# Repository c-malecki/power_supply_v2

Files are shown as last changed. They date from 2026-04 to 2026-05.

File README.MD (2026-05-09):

# Power Supply V2 (Prototype)

## Project Background

Building my own power supply has has been an ongoing and iterative project to explore and learn embedded systems. Designing and building my own tools seemed like a great way to work on something with a real use case and grow my knowledge and skill via iterative design and progressive loading of new concepts and methodologies in stages.

### Previous Iterations

The [first version](https://github.com/c-malecki/power_supply) served as a discovery phase, utilizing hardware modules primarily in order to gain a high-level understanding of power supply design and electrical engineering/embedded systems. Due to complications and limitations of the component selection (*particularly I2C issues with many undocumented modules and whether they have internal pull-up resistors*) and having learned enough to make more informed choices, I started working on V2 as the real prototype.

<figure>
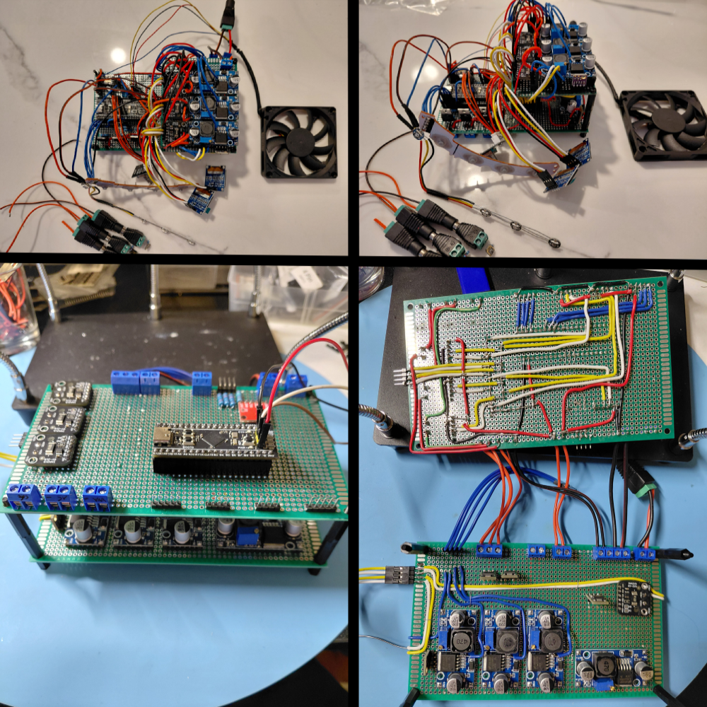
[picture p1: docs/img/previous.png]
Previous Iterations
  
  <figcaption>Some previous iterations and layouts that inevitably became a rat's nest.</figcaption>
</figure>

### V2 Learning Goals:

- __Use EDA software to create schematic diagrams__: Use KiCad 9 to create schematics, revise the design over the course of the project, and learn best practices in schematic diagramming
- __Design circuits using discrete component selections__: Hand select components and perform the calculations required to support intended operation as opposed to hardware modules (*with the exception of reusing OLED and temperature sensor modules*)
- __Increase datasheet and documentation fluency__: Relying on vendor sources primarily for application considerations and calculations

### V2 Exclusions:

- __PCB design:__ I am assembling this prototype using perfboard and handsoldering due to ease of error correction and rearrangement of circuits
- __Advanced Data Features:__ Although data will be read and displayed, I am leaving out advanced integrations like real-time communication with a host PC for logging and analyzing data. I intend to do a "V3" where I will do PCB design and add in support for more complex firmware features.

## V2 Core Features

*This list is subject to change as I continue to work through the prototyping process.*

### Power Rails
- Fixed 3.3V and 5V rails for external loads
- Variable 5V to 18V rail for external load
- Independent output for simultaneous connections
- PID control loop to ensure consistent and accurate output of power rails

### Safety Systems
- Continuous power and temperature monitoring
- Hardware and firmware based protections for reverse polarity, back EMF, overvoltage, overcurrent, and overtemperature
- Firmware controlled shutoffs in stages depending on severity of a fault (*e.g. individual power rail shutoff for external connections, full power rail shutoff for internal and external connections, full system shutoff*)
- RGB LED status indicators and debug blink codes
- Warning and error displays

### User Interface
- OLED for system menu containing configuration settings
- OLED for data display screens such as operating conditions
- Buttons for toggling external rails on/off and cycling through data display screens
- Rotary encoder for navigating system menus and making selections

## Hardware Design

### Component Selection

- [STM32G474RE Nucleo](https://www.st.com/resource/en/datasheet/stm32g474cb.pdf)
- 20V 3.25A Laptop Charging Brick with added 3A slow-blow fuse
- [TPS54302 buck converters](https://www.ti.com/lit/ds/symlink/tps54302.pdf)
- [MCP1700 LDOs](https://ww1.microchip.com/downloads/en/DeviceDoc/MCP1700-Data-Sheet-20001826F.pdf)
- [TPS22918 high side switches](https://www.ti.com/lit/ds/symlink/tps22918.pdf)
- [Voltage buffer](https://www.ti.com/lit/ds/symlink/sn74ahct125.pdf)
- [INA180Ax current sensors](https://www.ti.com/lit/ds/symlink/ina180.pdf)
- [SHT31-D temperature sensors](https://sensirion.com/media/documents/213E6A3B/63A5A569/Datasheet_SHT3x_DIS.pdf)
- [SSD1306 OLEDs](https://goldenmorninglcd.com/wp-content/plugins/pdf-poster/pdfjs-new/web/viewer.html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)
- [WS2812B LEDs](https://cdn.sparkfun.com/assets/e/6/1/f/4/WS2812B-LED-datasheet.pdf)

### Block Diagram

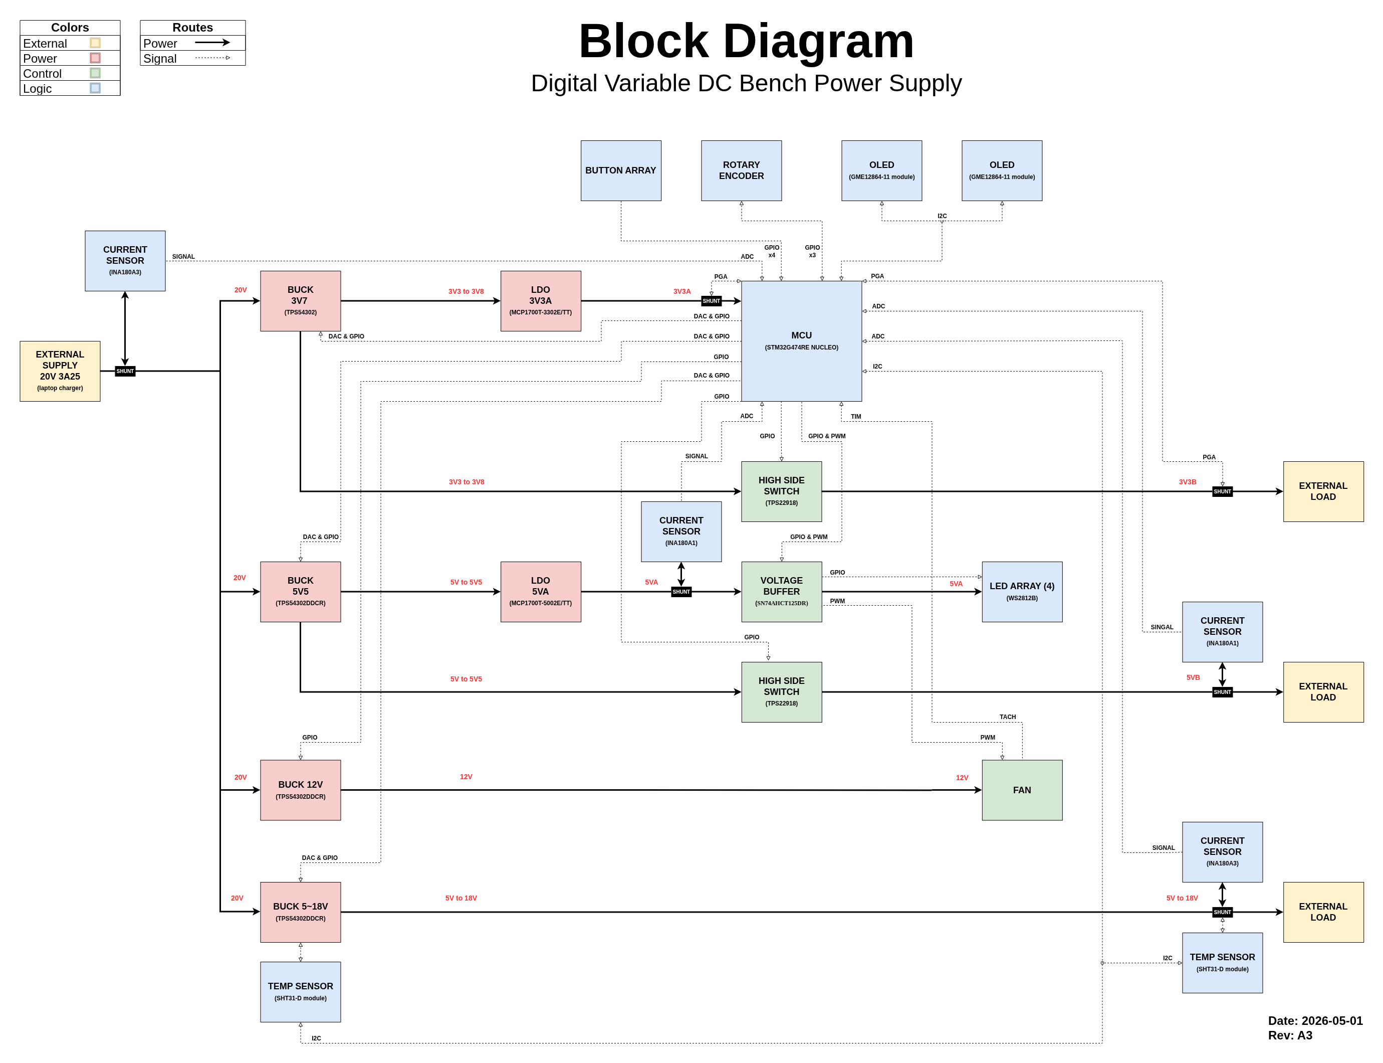
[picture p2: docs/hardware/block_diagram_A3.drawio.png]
Block Diagram


### Schematic

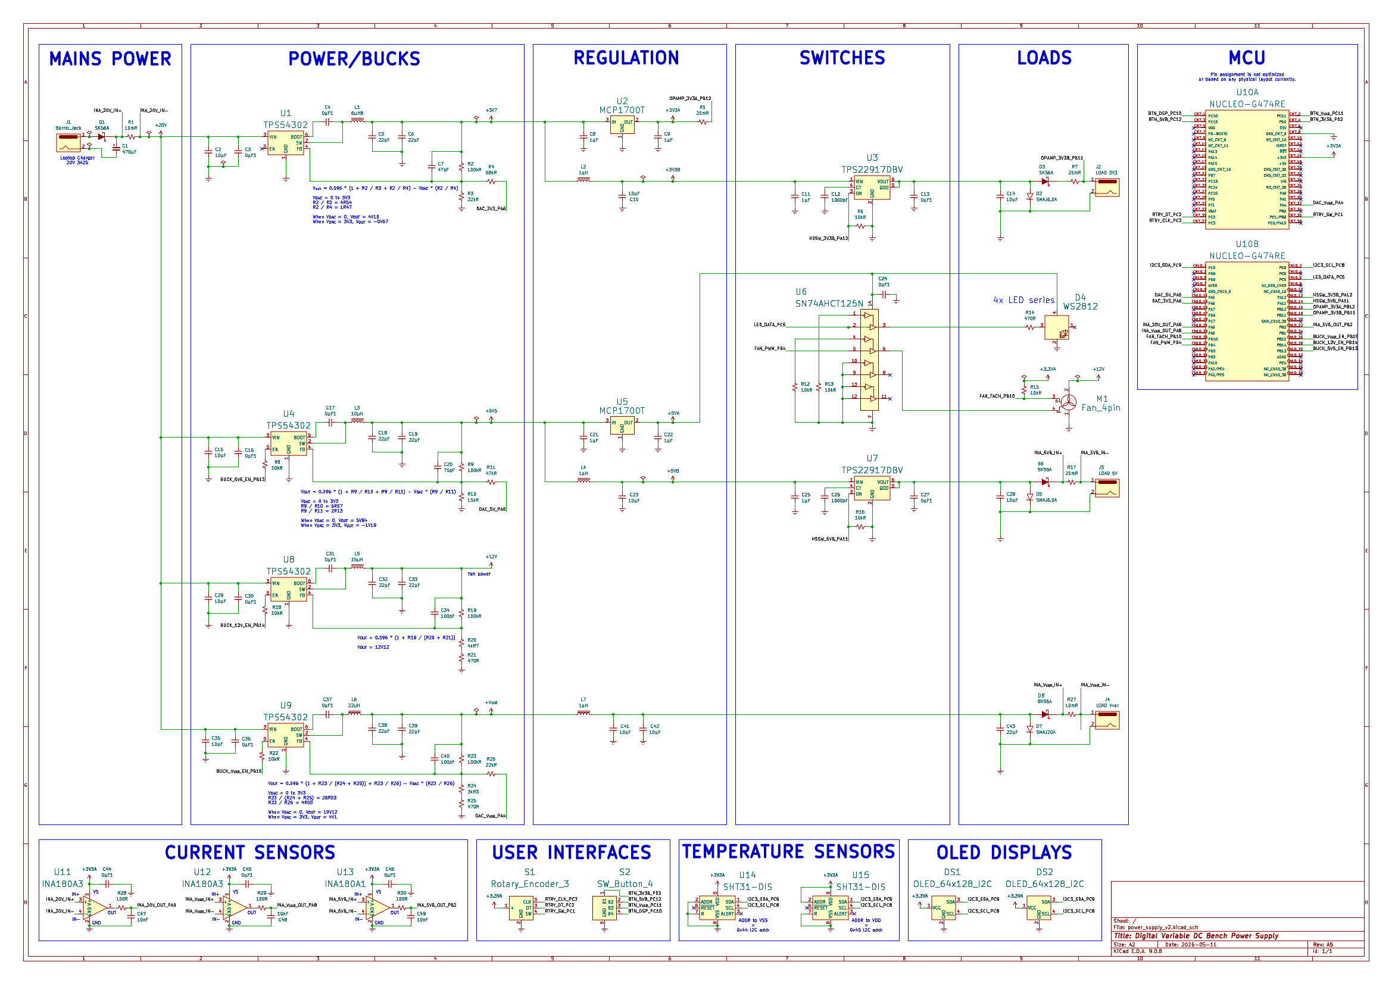
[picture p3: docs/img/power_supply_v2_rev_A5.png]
Schematic


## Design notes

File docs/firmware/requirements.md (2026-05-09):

bucks on/off
hssw on/off

current/voltage readings

temperature readings

change fan speed from temp

safety switches from current/voltage

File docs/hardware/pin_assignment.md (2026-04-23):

# Pin Assignments

## Overview

| Qty | GPIO Mode | PU/PD | Prph & Func |
| --- | --- | --- | --- |
| 2x | EXTI RE | PU | Rotary SW, Rotary DT |
| 4x | EXTI FE | PU | Button Array |
| 1x | Input | PU | Rotary CLK |
| 1x | AF DAC | ? | Vvar Buck EN |
| 1x | ? | ? | LED data |
| 3x | Output PP | ? | Fixed Bucks EN |
| 2x | AF PP | None | Fan Tach, Fan PWM
| 2x | AF OD | None | I2C: SCL + SDA |
| 2x | AF PGA ? | ? | 3V3 shunts |
| 4x | AF ADC ? | ? | 5V, 12V, Vvar shunts |

## By Peripheral

### Rotary Encoder

| MCU Pin | Prph Pin | GPIO Mode | PU/PD |
| --- | --- | --- | --- |
| ? | SW | EXTI Rising-Edge | Pull-up |
| ? | DT | EXTI Rising-Edge | Pull-up |
| ? | CLK | Input | Pull-up |

### Button Array

| MCU Pin | Prph Pin | GPIO Mode | PU/PD |
| --- | --- | --- | --- |
| ? | 1 | EXTI Falling-Edge | Pull-up |
| ? | 2 | EXTI Falling-Edge | Pull-up |
| ? | 3 | EXTI Falling-Edge | Pull-up |
| ? | 4 | EXTI Falling-Edge | Pull-up |

### Buck Converters

| MCU Pin | Prph Pin | GPIO Mode | PU/PD |
| --- | --- | --- | --- |
| ? | EN | Output Push-Pull | ? |
| ? | EN | Output Push-Pull | ? |
| ? | EN | Output Push-Pull | ? |

### Current Sensors

| MCU Pin | Prph Pin | GPIO Mode | PU/PD |
| --- | --- | --- | --- |
| ? | 1 Out | AF ADC ? | ? |
| ? | 1 Out | AF ADC ? | ? |
| ? | 1 Out | AF ADC ? | ? |
| ? | 1 Out | AF ADC ? | ? |

## Protocol

### I2C

### Temperature Sensors

| MCU Pin | Prph Pin | GPIO Mode | PU/PD |
| --- | --- | --- | --- |
| ? | 1 Out | AF ADC ? | ? |
| ? | 1 Out | AF ADC ? | ? |
| ? | 1 Out | AF ADC ? | ? |
| ? | 1 Out | AF ADC ? | ? |

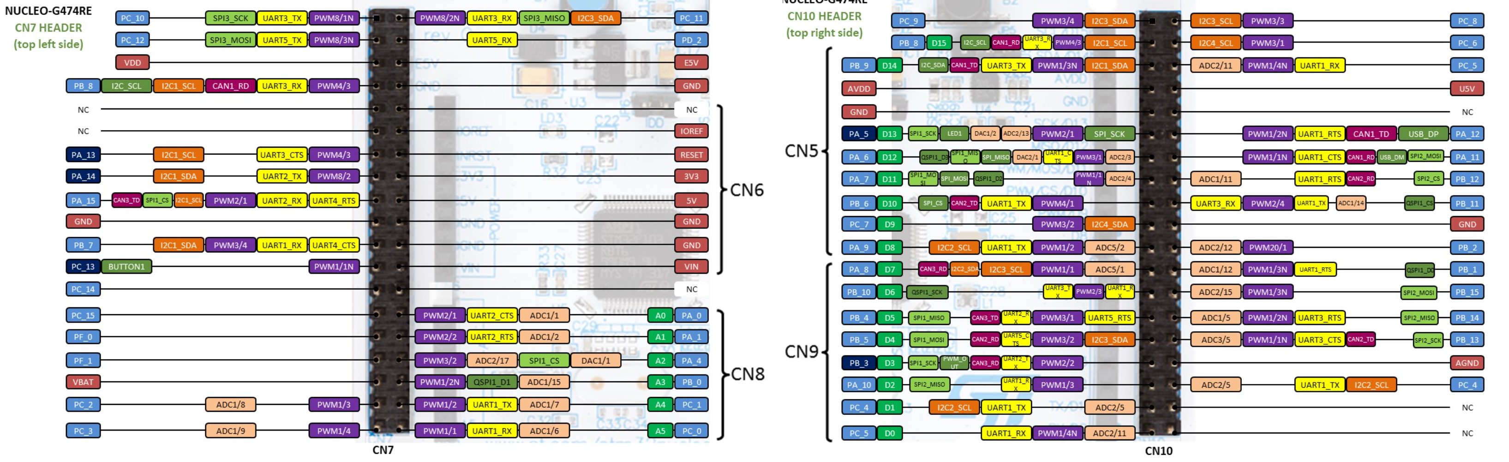
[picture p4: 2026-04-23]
docs/datasheets/microcontroller/STM32G474RE_Pinout.png

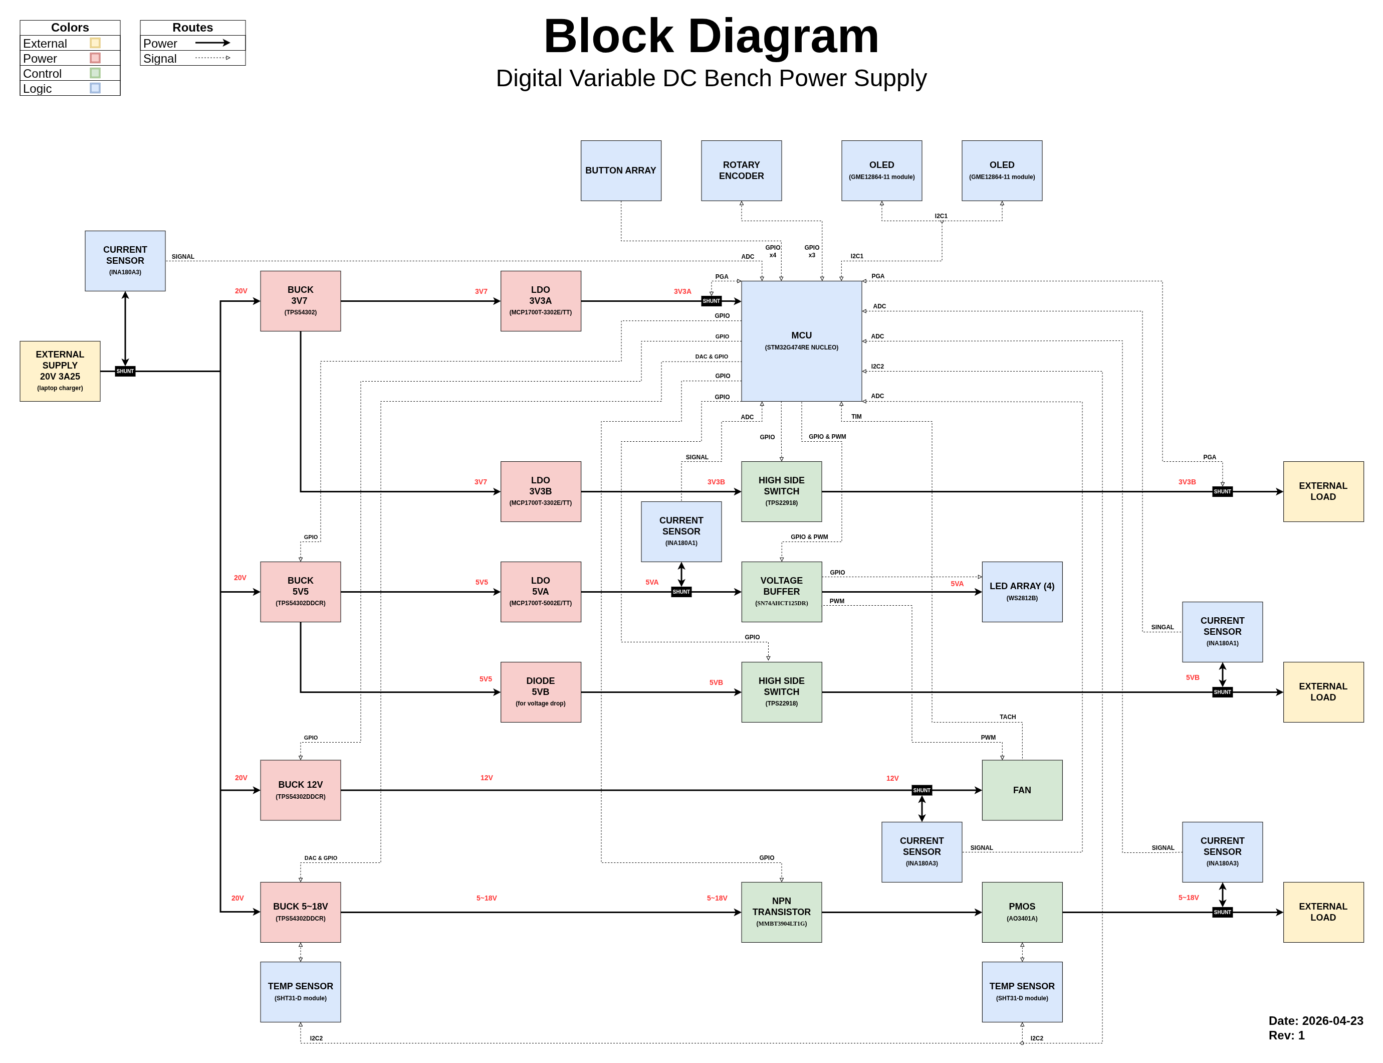
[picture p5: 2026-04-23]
docs/hardware/block_diagram_A1.png

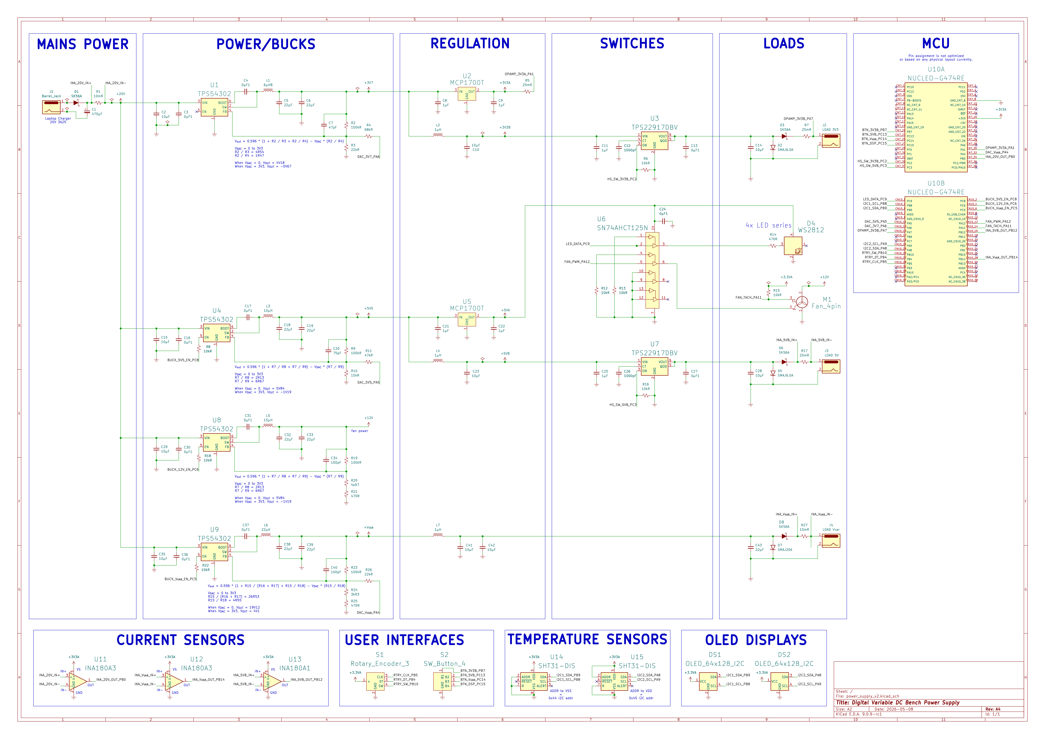
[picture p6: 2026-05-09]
docs/img/power_supply_v2_rev_A4.png

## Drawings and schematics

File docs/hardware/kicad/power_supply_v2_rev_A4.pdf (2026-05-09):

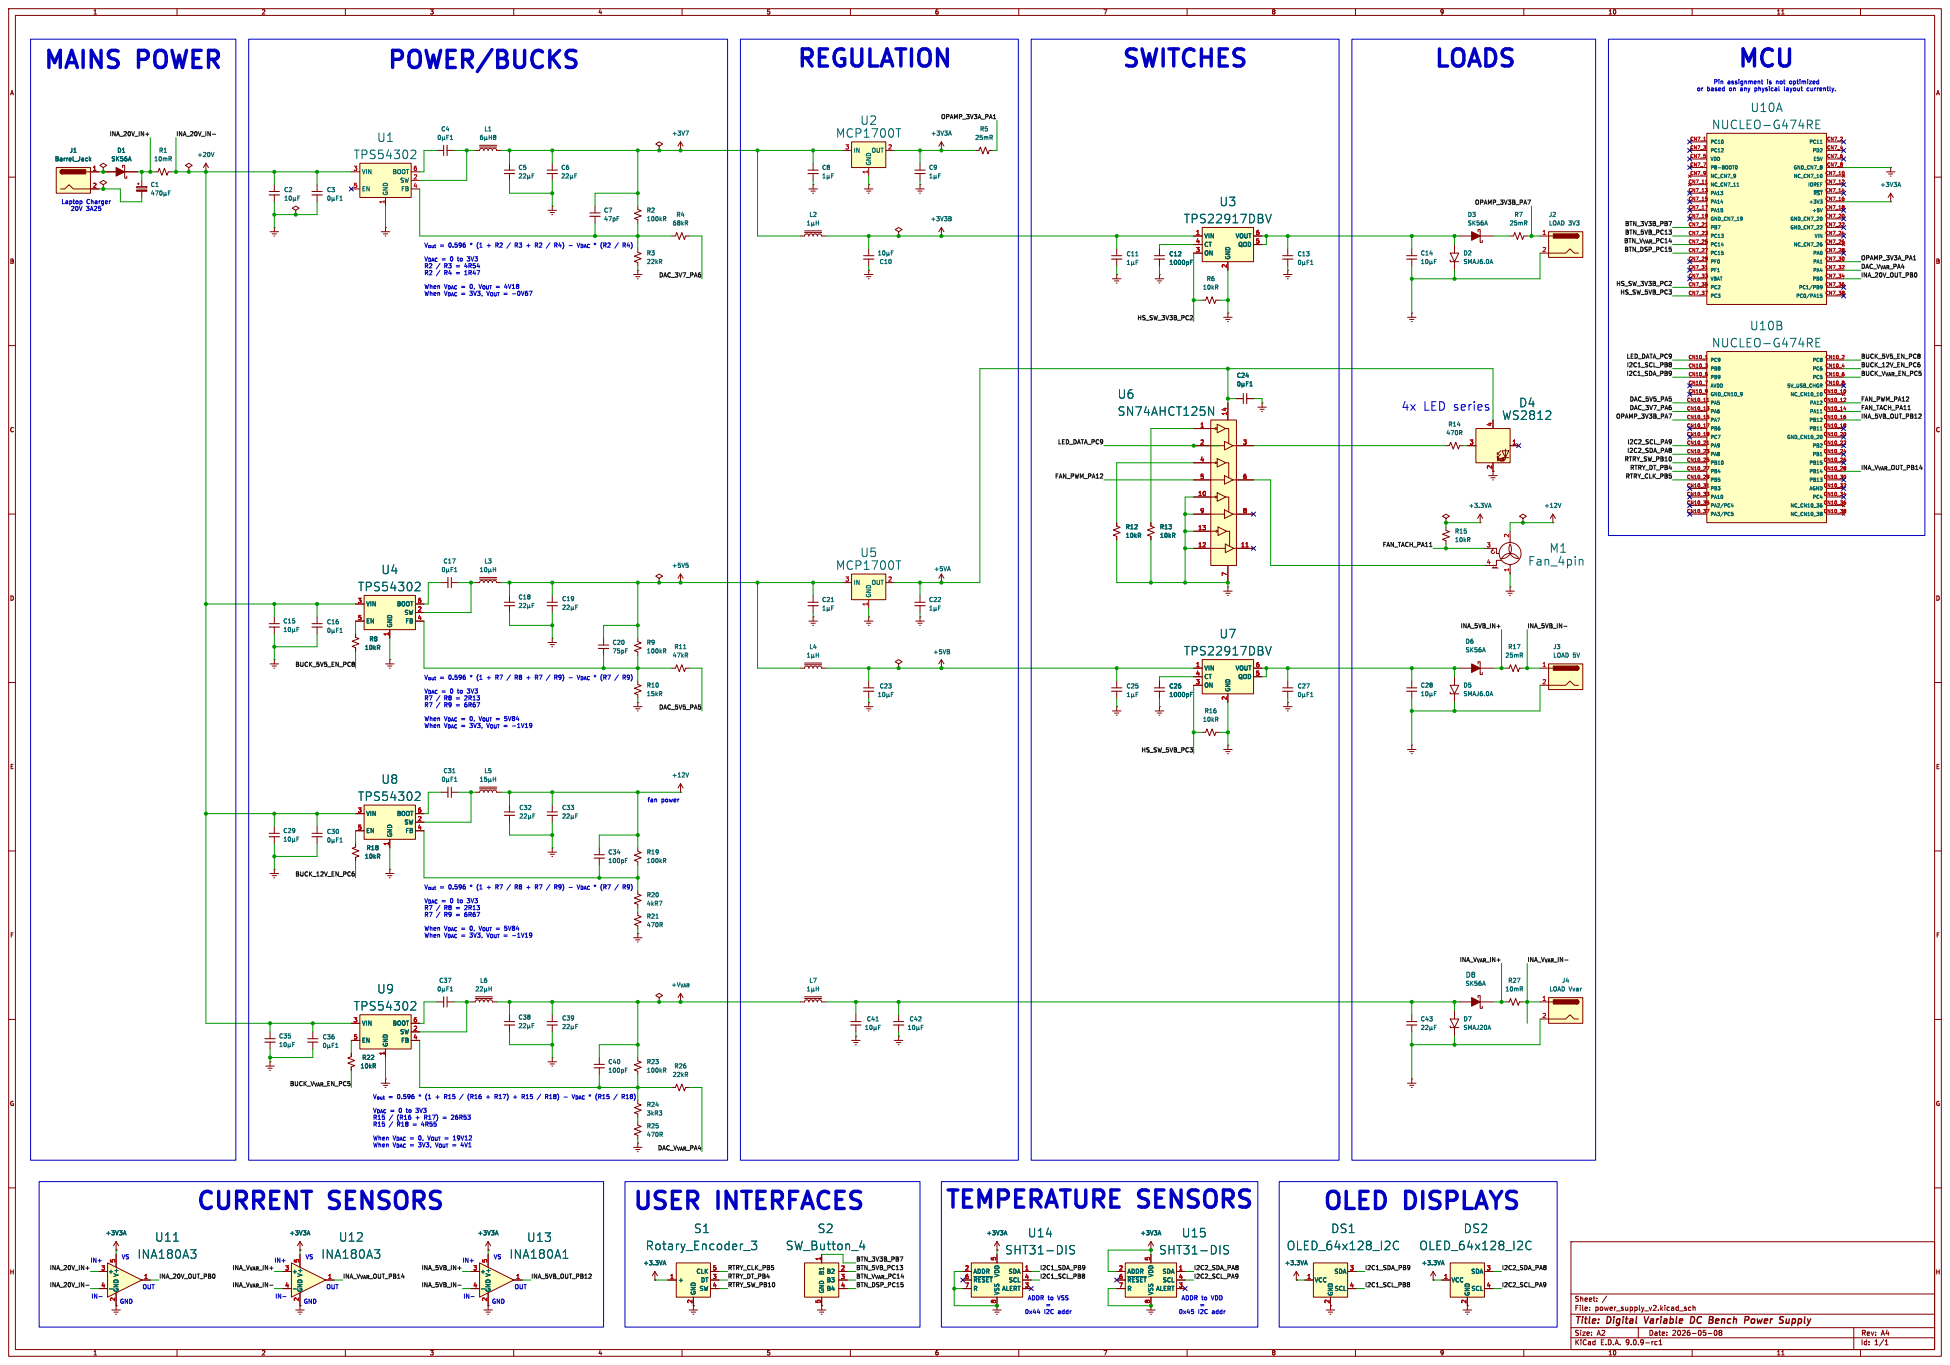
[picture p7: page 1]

0x44 I2C addr OUT MAINS POWER

V_{DAC} = 0 to 3V3 R7 / R8 = 2R13 R7 / R9 = 6R67 When V_{DAC} = 0, V_{OUT} = 5V84 When V_{DAC} = 3V3, V_{OUT} = -1V19

V_{DAC} = 0 to 3V3 R7 / R8 = 2R13 R7 / R9 = 6R67 When V_{DAC} = 0, V_{OUT} = 5V84 When V_{DAC} = 3V3, V_{OUT} = -1V19 OUT

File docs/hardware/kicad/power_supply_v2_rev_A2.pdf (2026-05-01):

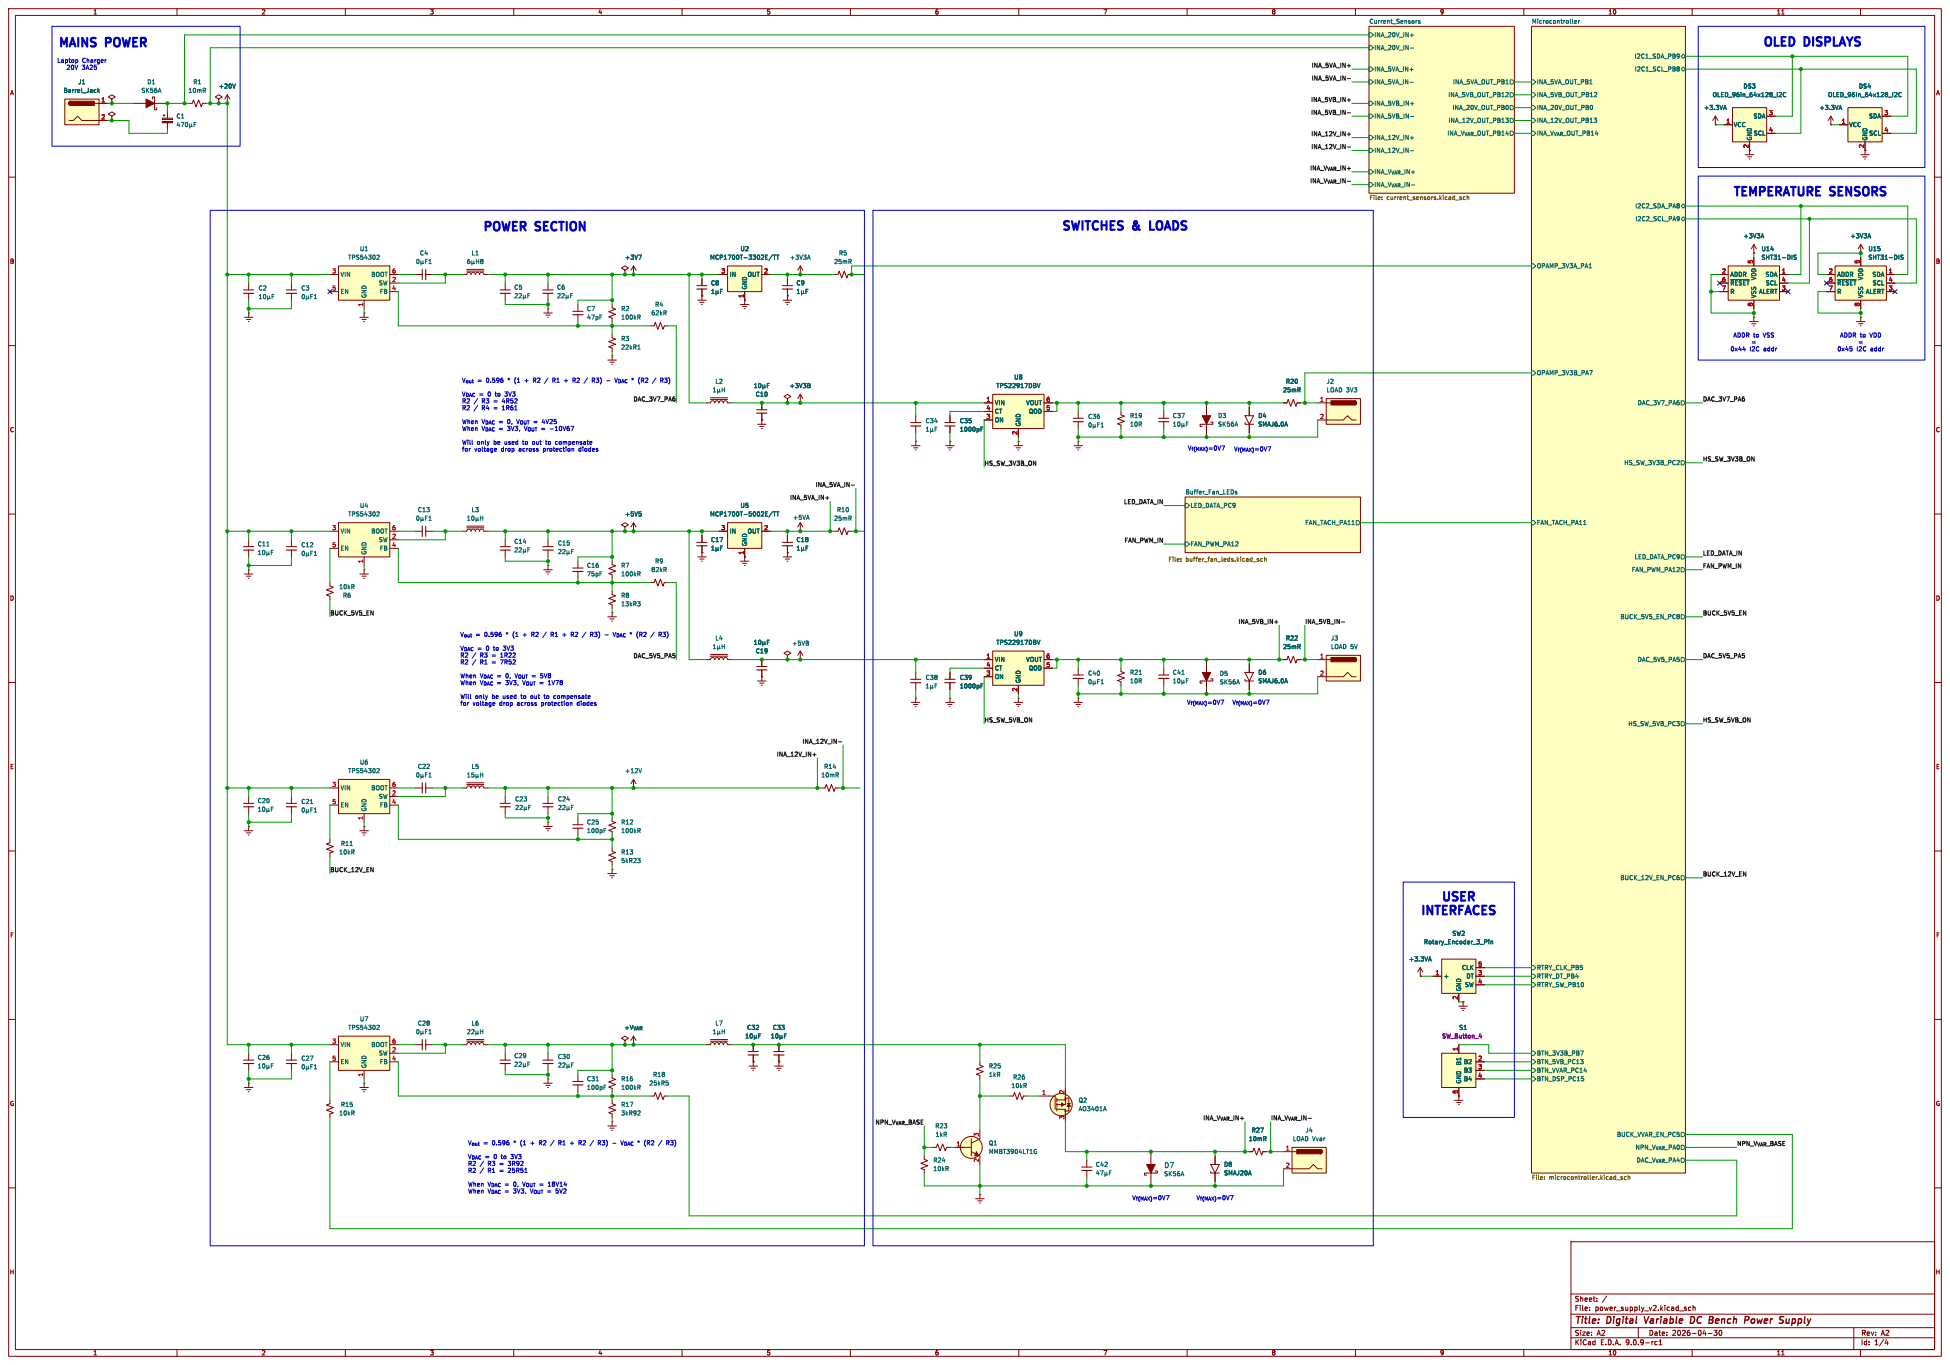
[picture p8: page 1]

Laptop Charger 20V 3A25 MAINS POWER

POWER SECTION
alter modules or remove the resistors. V_{out}= 0.596 * (1 + R2 / R1 + R2 / R3) - V_{DAC} * (R2 / R3)

V_{DAC} = 0 to 3V3 R2 / R3 = 4R52 R2 / R4 = 1R61 When V_{DAC} = 0, V_{OUT} = 4V25 When V_{DAC} = 3V3, V_{OUT} = -10V67 Will only be used to out to compensate

V_{DAC} = 0 to 3V3 R2 / R3 = 1R22 R2 / R1 = 7R52 When V_{DAC} = 0, V_{OUT} = 5V8 When V_{DAC} = 3V3, V_{OUT} = 1V78 Will only be used to out to compensate

V_{DAC} = 0 to 3V3 R2 / R3 = 3R92 R2 / R1 = 25R51 When V_{DAC} = 0, V_{OUT} = 18V14 When V_{DAC} = 3V3, V_{OUT} = 5V2

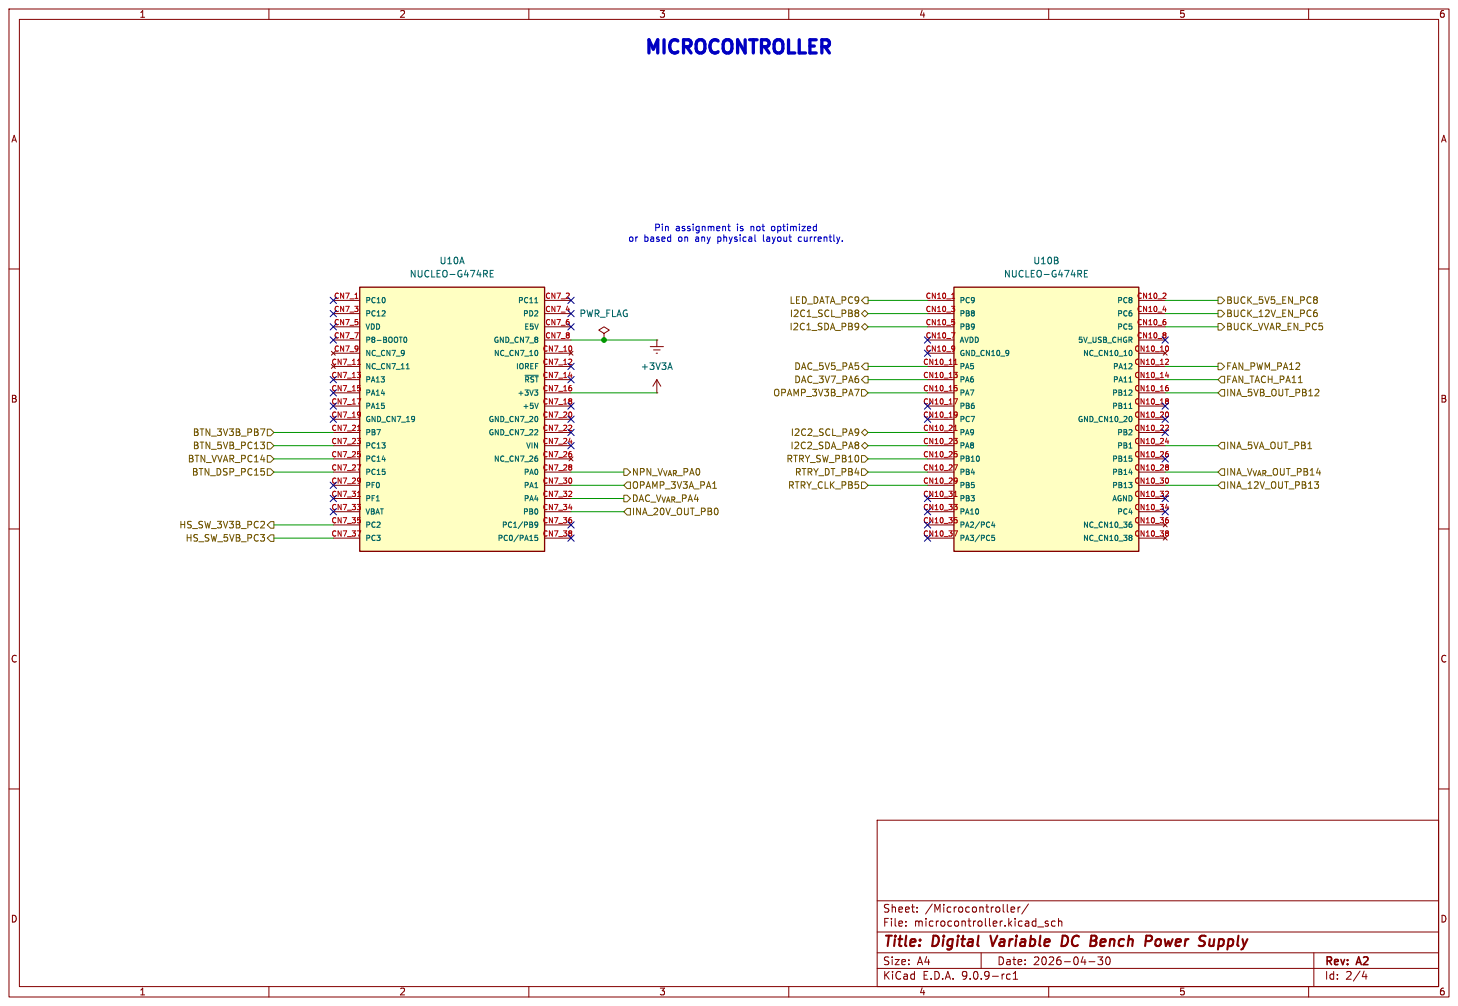
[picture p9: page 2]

File: microcontroller.kicad_sch Sheet: /Microcontroller/
Id: 2/4 Title: Digital Variable DC Bench Power Supply

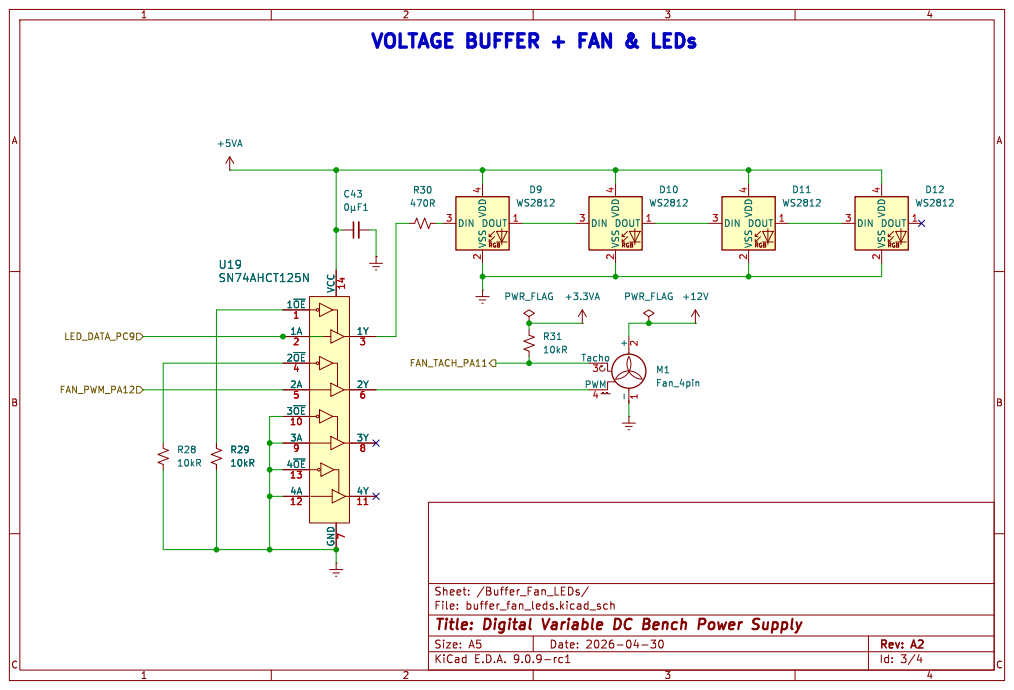
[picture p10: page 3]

11 U19 SN74AHCT125N

Id: 3/4 Title: Digital Variable DC Bench Power Supply

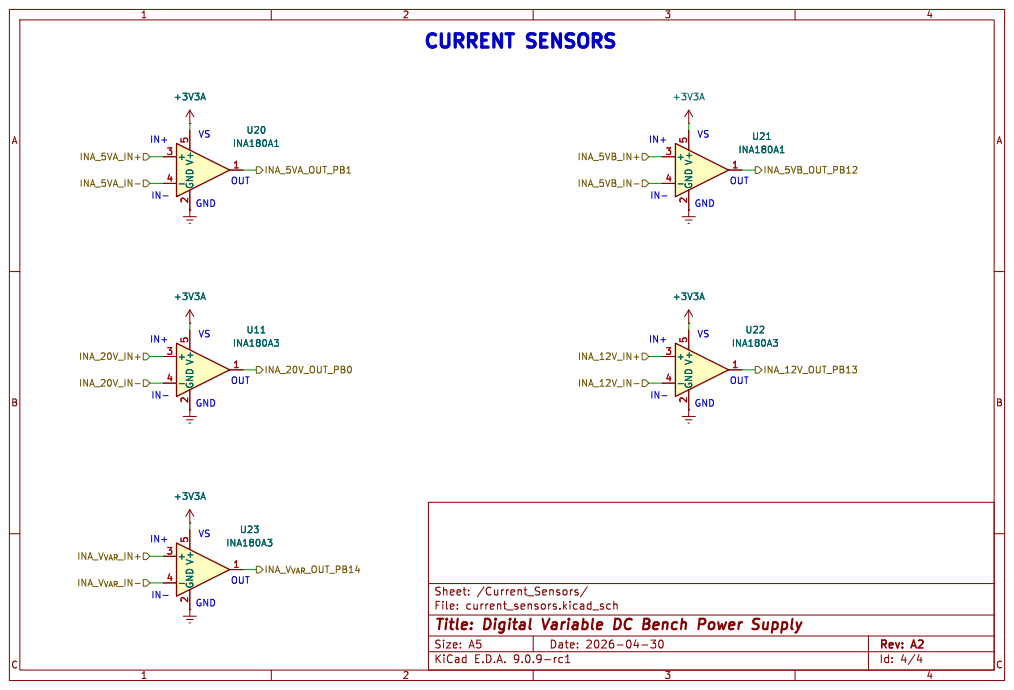
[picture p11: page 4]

File: current_sensors.kicad_sch Sheet: /Current_Sensors/
Id: 4/4 Title: Digital Variable DC Bench Power Supply

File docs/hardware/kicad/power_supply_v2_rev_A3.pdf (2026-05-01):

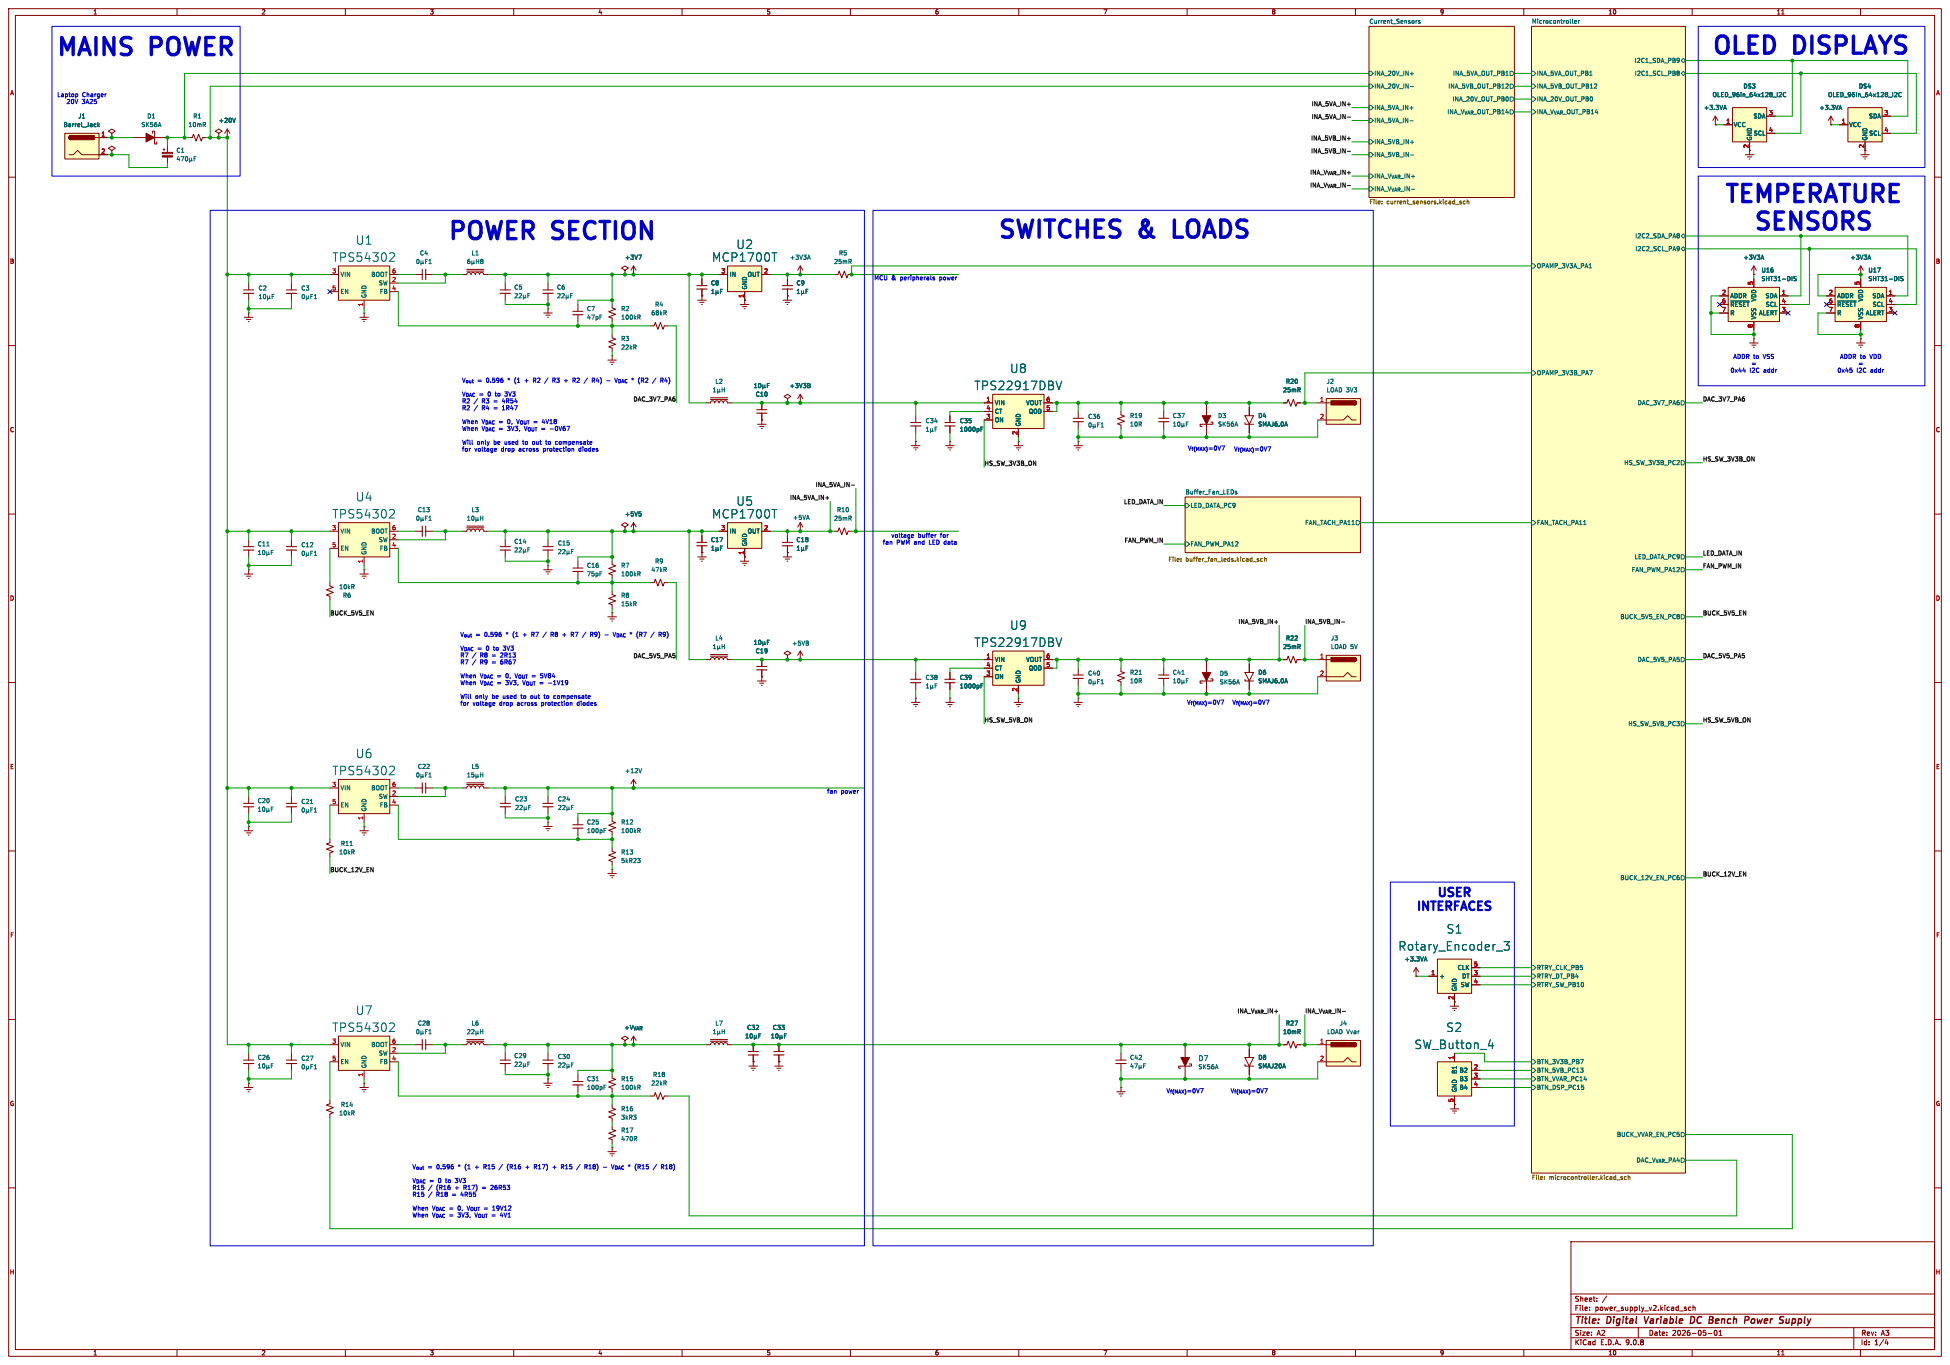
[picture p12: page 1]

alter modules or remove the resistors. OLED DISPLAYS

V_{DAC} = 0 to 3V3 R2 / R3 = 4R54 R2 / R4 = 1R47 When V_{DAC} = 0, V_{OUT} = 4V18 When V_{DAC} = 3V3, V_{OUT} = -0V67 Will only be used to out to compensate

V_{DAC} = 0 to 3V3 R7 / R8 = 2R13 R7 / R9 = 6R67 When V_{DAC} = 0, V_{OUT} = 5V84 When V_{DAC} = 3V3, V_{OUT} = -1V19 Will only be used to out to compensate

V_{DAC} = 0 to 3V3 R15 / (R16 + R17) = 26R53 R15 / R18 = 4R55 When V_{DAC} = 0, V_{OUT} = 19V12 When V_{DAC} = 3V3, V_{OUT} = 4V1

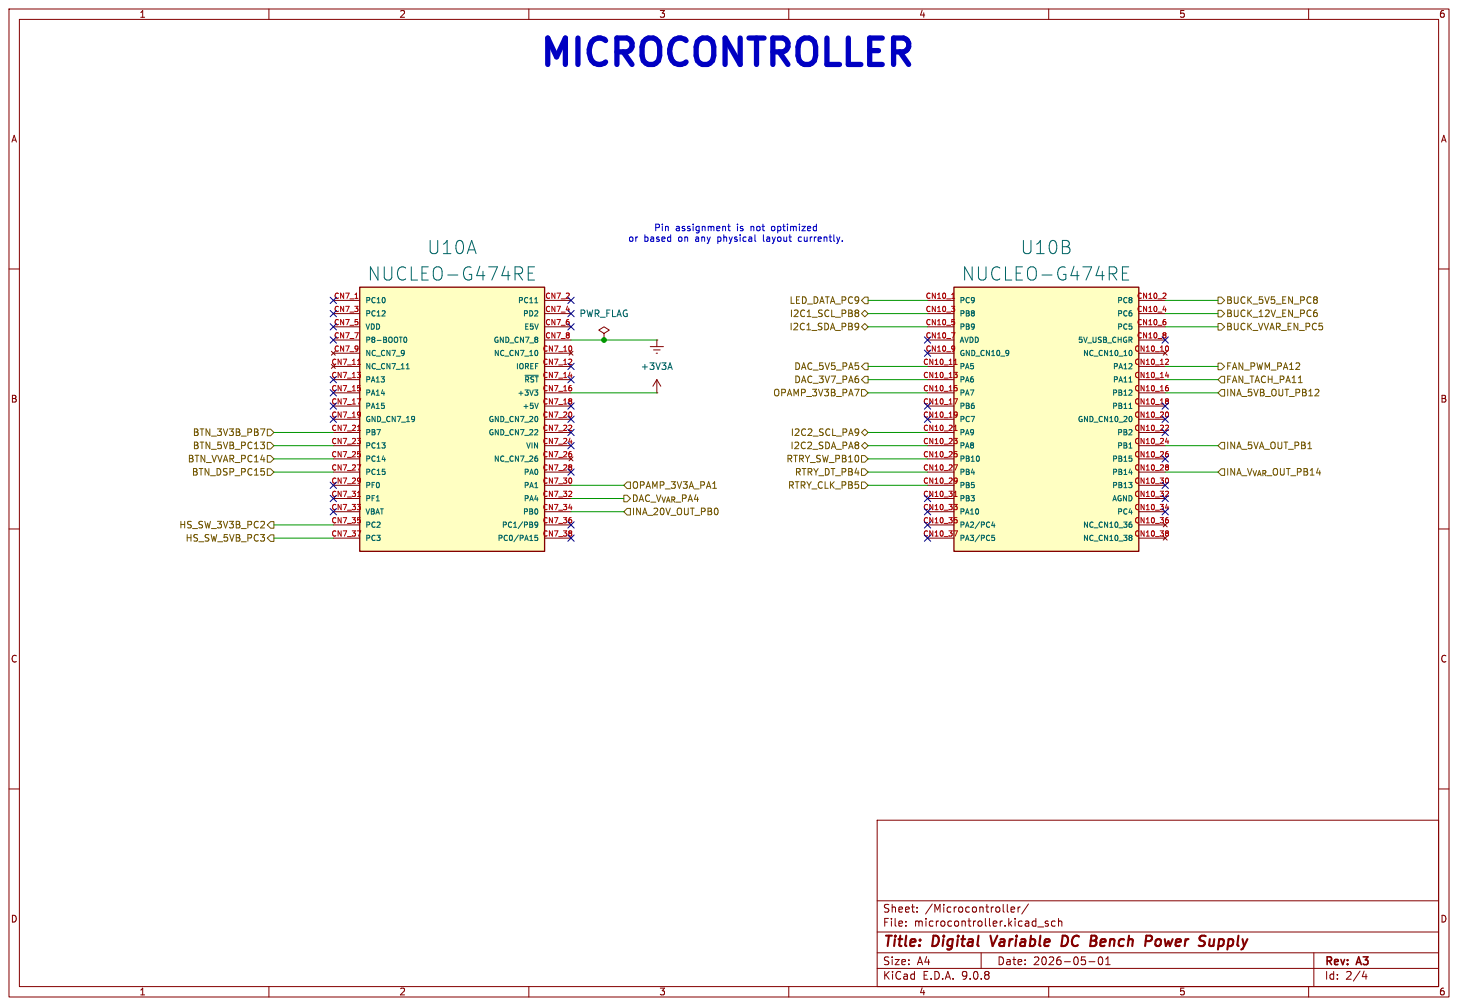
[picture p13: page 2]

File: microcontroller.kicad_sch Sheet: /Microcontroller/
Id: 2/4 Title: Digital Variable DC Bench Power Supply

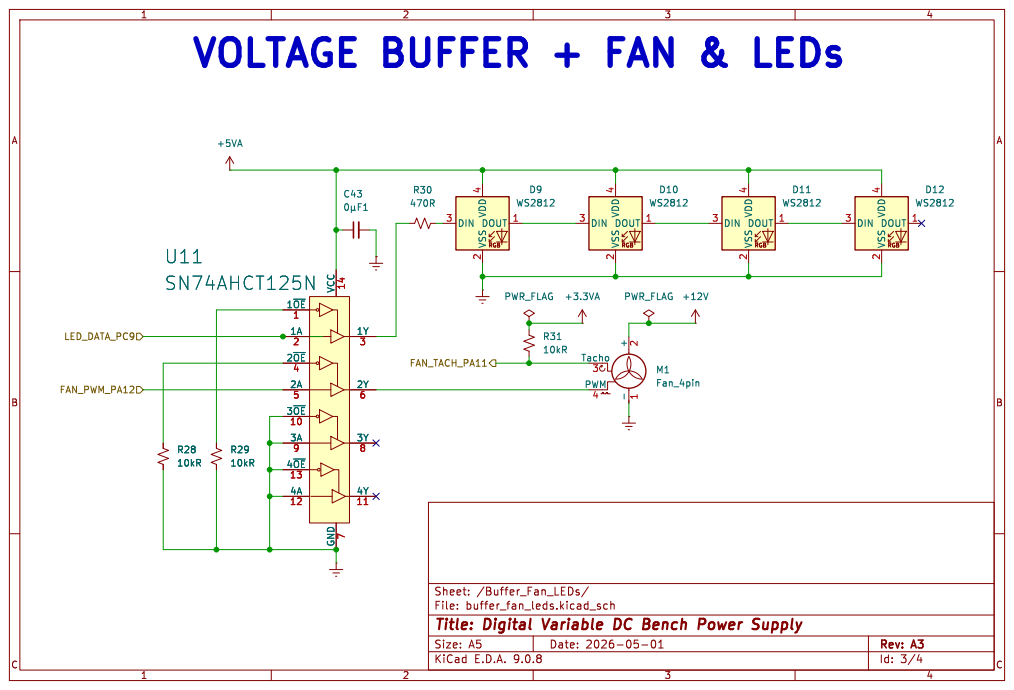
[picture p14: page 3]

Id: 3/4 Title: Digital Variable DC Bench Power Supply

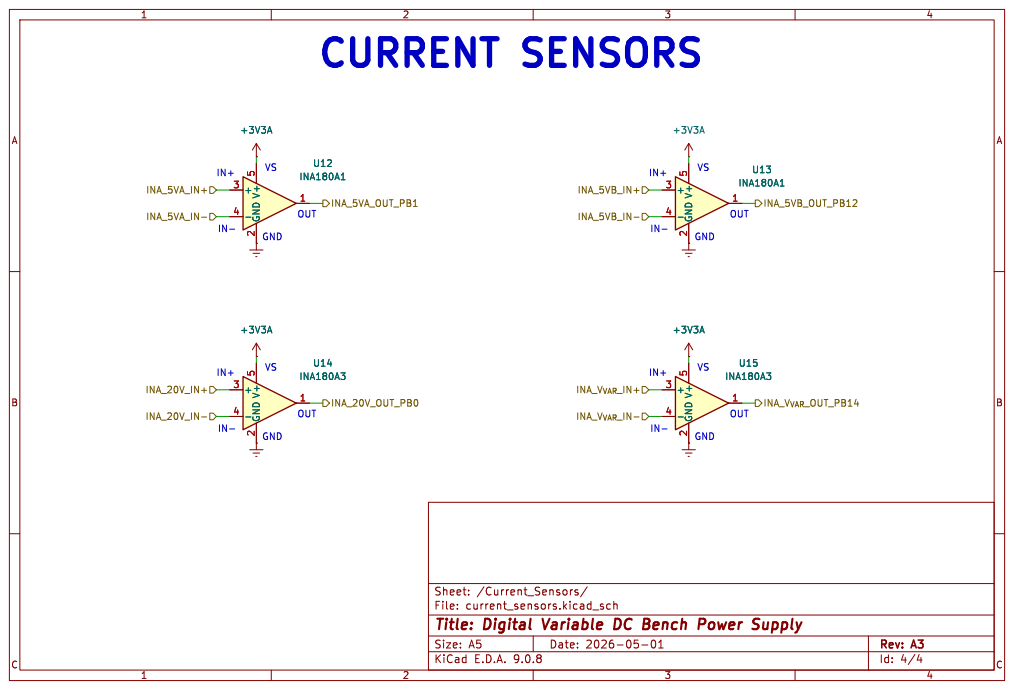
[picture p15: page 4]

Id: 4/4 Title: Digital Variable DC Bench Power Supply

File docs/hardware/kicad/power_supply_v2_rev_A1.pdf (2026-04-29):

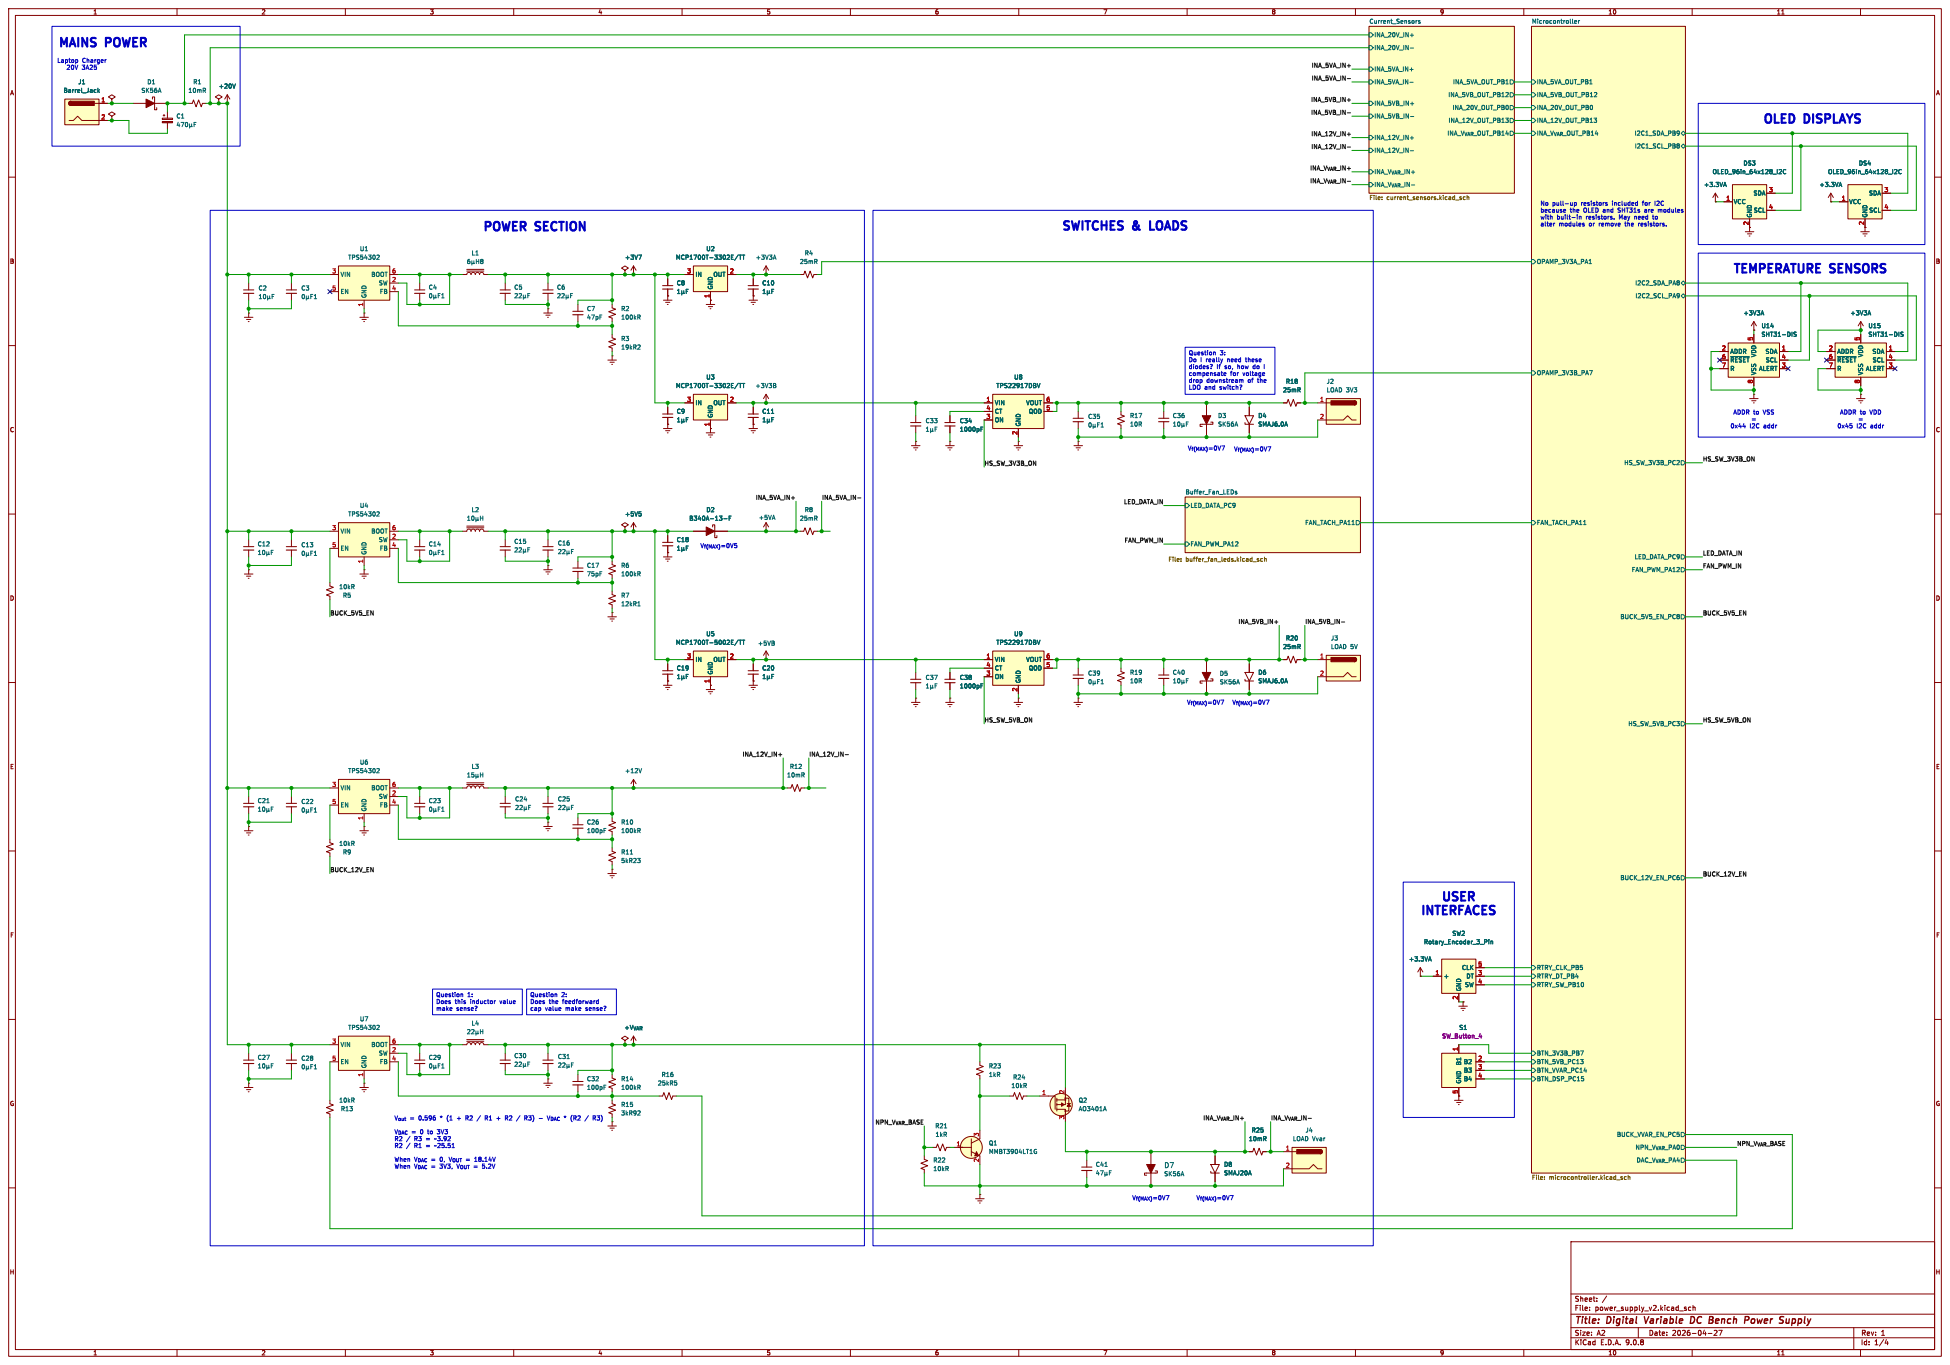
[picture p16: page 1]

alter modules or remove the resistors.

Question 3: Do I really need these
D6SMAJ6.0A C36

V_{DAC} = 0 to 3V3 R2 / R3 = ~3.92 R2 / R1 = ~25.51 When V_{DAC} = 0, V_{OUT} = 18.14V When V_{DAC} = 3V3, V_{OUT} = 5.2V

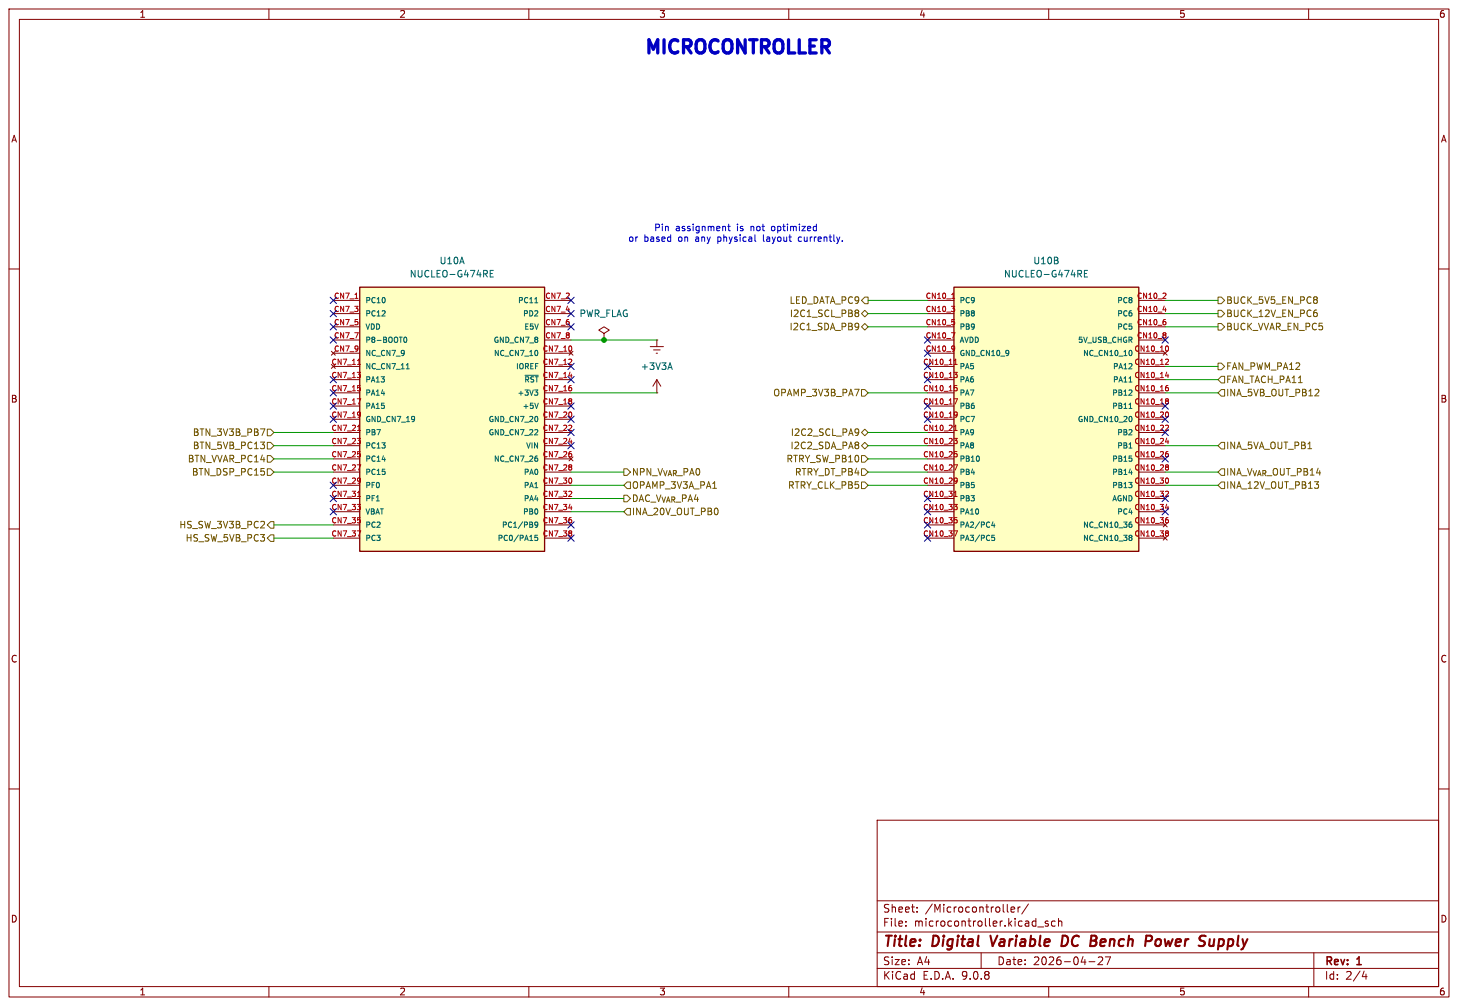
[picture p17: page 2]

File: microcontroller.kicad_sch Sheet: /Microcontroller/
Id: 2/4 Title: Digital Variable DC Bench Power Supply

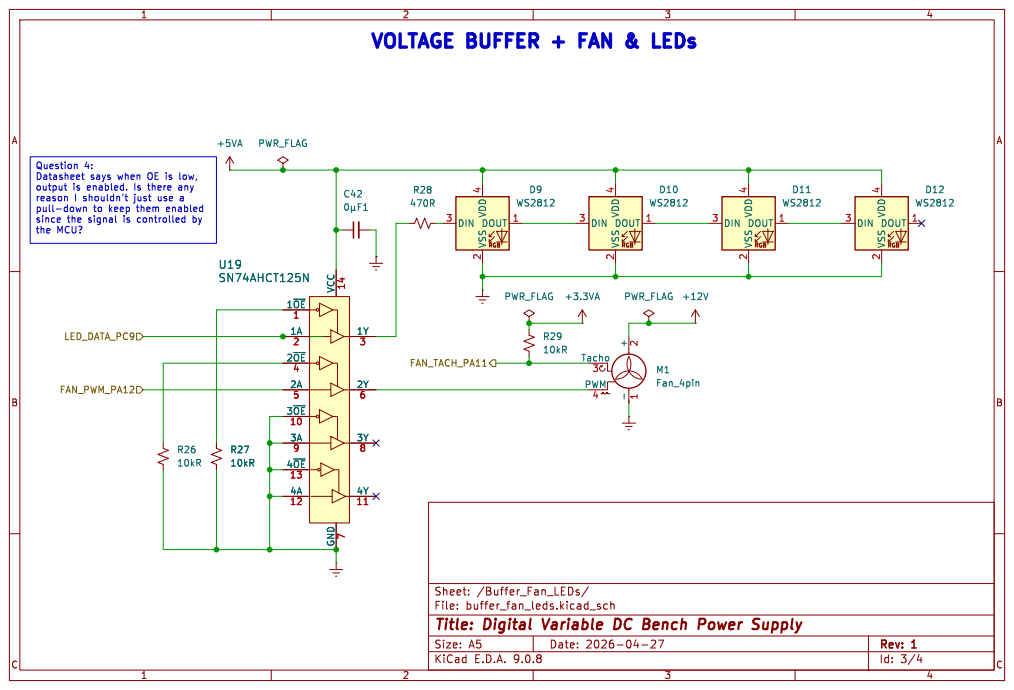
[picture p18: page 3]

11 U19 SN74AHCT125N

Id: 3/4 Title: Digital Variable DC Bench Power Supply


Id: 4/4 Title: Digital Variable DC Bench Power Supply

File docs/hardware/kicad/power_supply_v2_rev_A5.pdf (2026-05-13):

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

V_{DAC} = 0 to 3V3 R9 / R10 = 6R67 R9 / R11 = 2R13 When V_{DAC} = 0, V_{OUT} = 5V84 When V_{DAC} = 3V3, V_{OUT} = -1V19

V_{OUT} = 0.596 * (1 + R23 / (R24 + R25)) + R23 / R26) - V_{DAC} * (R23 / R26)
V_{DAC} = 0 to 3V3 R23 / (R24 + R25) = 26R53 R23 / R26 = 4R55 When V_{DAC} = 0, V_{OUT} = 19V12 When V_{DAC} = 3V3, V_{OUT} = 4V1

alter modules or remove the resistors. OLED DISPLAYS

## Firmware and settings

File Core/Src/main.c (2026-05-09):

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
/* Includes ------------------------------------------------------------------*/
#include "main.h"
#include "adc.h"
#include "dac.h"
#include "dma.h"
#include "i2c.h"
#include "opamp.h"
#include "tim.h"
#include "gpio.h"

/* USER CODE BEGIN Includes */
#include <stdint.h>
#include <stdio.h>

#include "SEGGER_RTT.h"
#include "app.h"
#include "tests.h"
/* USER CODE END Includes */


/* USER CODE BEGIN PV */
static App_t app;
/* USER CODE END PV */

void SystemClock_Config(void);
/* USER CODE BEGIN 0 */
int _write(int file, char *ptr, int len)
{
    SEGGER_RTT_Write(0, ptr, len);
    return len;
}
/* USER CODE END 0 */

/**
  * @brief  The application entry point.
  * @retval int
  */
int main(void)
{

  /* MCU Configuration--------------------------------------------------------*/

  /* Reset of all peripherals, Initializes the Flash interface and the Systick. */
  HAL_Init();

  /* Configure the system clock */
  SystemClock_Config();

  /* Initialize all configured peripherals */
  MX_GPIO_Init();
  MX_DMA_Init();
  MX_ADC2_Init();
  MX_ADC5_Init();
  MX_DAC1_Init();
  MX_DAC2_Init();
  MX_TIM2_Init();
  MX_TIM3_Init();
  MX_TIM6_Init();
  MX_ADC1_Init();
  MX_I2C3_Init();
  MX_OPAMP4_Init();
  MX_OPAMP6_Init();
  /* USER CODE BEGIN 2 */
    app.state = APP_STATE_INIT;
    App_Init(&app, &hi2c3);

    Test_Power(&app);
  /* USER CODE END 2 */

  /* Infinite loop */
  /* USER CODE BEGIN WHILE */
    while (1) {

    /* USER CODE END WHILE */

    /* USER CODE BEGIN 3 */
    }
  /* USER CODE END 3 */
}

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
/* USER CODE BEGIN 4 */
void HAL_TIM_IC_CaptureCallback(TIM_HandleTypeDef *htim)
{
    // TODO: issue #28: set flag and handle logic outside of interrupt
    Temp_Ctrl_t *ctrl = &app.temperature_controller;
    if (htim->Instance == TIM5 && htim->Channel == HAL_TIM_ACTIVE_CHANNEL_2) {
        ctrl->fan.value_cur = HAL_TIM_ReadCapturedValue(htim, TIM_CHANNEL_2);
        ctrl->fan.last_tick = HAL_GetTick();

        if (!ctrl->fan.first_cb) {
            if (ctrl->fan.value_cur >= ctrl->fan.value_last) {
                ctrl->fan.value_diff = ctrl->fan.value_cur - ctrl->fan.value_last;
            } else {
                ctrl->fan.value_diff =
                    (0xFFFFFFFF - ctrl->fan.value_last) + ctrl->fan.value_cur + 1;
            }

            if (ctrl->fan.value_diff > 0) {
                ctrl->fan.rpm = 30000000.0f / (float)ctrl->fan.value_diff;
            }
        }

        ctrl->fan.value_last = ctrl->fan.value_cur;
        ctrl->fan.first_cb = 0;
    }
}

void HAL_TIM_PWM_PulseFinishedCallback(TIM_HandleTypeDef *htim)
{
    if (htim->Instance == TIM2)
        HAL_TIM_PWM_Stop_DMA(htim, TIM_CHANNEL_2);
}

void HAL_GPIO_EXTI_Callback(uint16_t GPIO_Pin)
{
    // static uint32_t last_press_rotary = 0;
    static uint32_t last_press_3v3 = 0;
    static uint32_t last_press_5v = 0;
    static uint32_t last_press_var = 0;
    static uint32_t last_press_menu = 0;
    uint32_t now = HAL_GetTick();

    switch (GPIO_Pin) {

    case BTN_VVAR_TOGGLE_Pin:
    {
        // TODO: issue #30: adjust debounce time to get buttons to stable toggle
        if (now - last_press_var < 75) {
            return;
        }
        last_press_var = now;
        app.power_controller.channels[PWR_CHAN_VVAR].toggle_pending = true;
        printf("GPIO_BTN_VVAR\r\n\n");
        break;
    }

    case BTN_5VB_TOGGLE_Pin:
    {
        if (now - last_press_5v < 75) {
            return;
        }
        last_press_5v = now;
        app.power_controller.channels[PWR_CHAN_5V].toggle_pending = true;
        printf("GPIO_BTN_5V\r\n\n");
        break;
    }

    case BTN_3V3B_TOGGLE_Pin:
    {
        if (now - last_press_3v3 < 75) {
            return;
        }
        last_press_3v3 = now;
        app.power_controller.channels[PWR_CHAN_3V3].toggle_pending = true;
        printf("GPIO_BTN_3V3\r\n\n");
        break;
    }

    case BTN_DSP_TOGGLE_Pin:
    {
        if (now - last_press_menu < 75) {
            return;
        }
        last_press_menu = now;
        printf("GPIO_BTN_DSP\r\n\n");
        break;
    }

        // case RTRY_SW_Pin:
        //     if (now - last_press_rotary < 50)
        //         return;
        //     last_press_rotary = now;
        //     app.power_controller->chan_var->rotary.pressed = true;
        //     break;

        // case BTN_DSP_MENU_Pin:
        // {
        // TODO: update display to show menu
        // rotary now becomes control
        // }
    }
}
/* USER CODE END 4 */
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


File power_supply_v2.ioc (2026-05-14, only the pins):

Mcu.UserName=STM32G474RETx
PA0.GPIO_Label=NC
PA0.Signal=GPIO_Input
PA1.GPIO_Label=NC
PA1.Signal=GPIO_Input
PA10.GPIO_Label=NC
PA10.Signal=GPIO_Input
PA11.GPIO_Label=HSSW_5VB
PA11.Signal=GPIO_Output
PA12.GPIO_Label=HSSW_3V3B
PA12.Signal=GPIO_Output
PA13.Signal=SYS_JTMS-SWDIO
PA14.Signal=SYS_JTCK-SWCLK
PA15.GPIO_Label=NC
PA15.Signal=GPIO_Input
PA2.GPIO_Label=NC
PA2.Signal=GPIO_Input
PA3.GPIO_Label=NC
PA3.Signal=GPIO_Input
PA4.GPIO_Label=BUCK_VVAR_DAC
PA4.Signal=COMP_DAC11_group
PA5.GPIO_Label=BUCK_5V_DAC
PA5.Signal=COMP_DAC12_group
PA6.GPIO_Label=BUCK_3V3_DAC
PA6.Signal=COMP_DAC21_group
PA7.GPIO_Label=NC
PA7.Signal=GPIO_Input
PA8.GPIO_Label=INA_VVAR_ADC5_IN1
PA8.Signal=ADC5_IN1
PA9.GPIO_Label=INA_20V_ADC5_IN2
PA9.Signal=ADC5_IN2
PB0.GPIO_Label=NC
PB0.Signal=GPIO_Input
PB1.GPIO_Label=NC
PB1.Signal=GPIO_Output
PB10.GPIO_Label=FAN_TACH_TIM2CH3
PB10.Signal=S_TIM2_CH3
PB11.GPIO_Label=OPAMP_3V3B_ADC1_IN14
PB11.Signal=SharedAnalog_PB11
PB12.GPIO_Label=OPAMP_3V3A_ADC1_IN11
PB12.Signal=SharedAnalog_PB12
PB13.GPIO_Label=BUCK_5V_EN
PB13.Signal=GPIO_Output
PB14.GPIO_Label=BUCK_12V_EN
PB14.Signal=GPIO_Output
PB15.GPIO_Label=BUCK_VVAR_EN
PB15.Signal=GPIO_Output
PB2.GPIO_Label=INA_5VB_ADC2_IN12
PB2.Signal=ADC2_IN12
PB3.GPIO_Label=T_SWO
PB3.Signal=SYS_JTDO-SWO
PB4.GPIO_Label=FAN_PWM_TIM3_CH1
PB4.Signal=S_TIM3_CH1
PB5.GPIO_Label=NC
PB5.Signal=GPIO_Input
PB6.GPIO_Label=NC
PB6.Signal=GPIO_Input
PB7.GPIO_Label=NC
PB7.Signal=GPIO_Input
PB8-BOOT0.GPIO_Label=NC
PB8-BOOT0.Signal=GPIO_Input
PB9.GPIO_Label=NC
PB9.Signal=GPIO_Input
PC0.GPIO_Label=NC
PC0.Signal=GPIO_Input
PC1.GPIO_Label=RTRY_SW
PC1.Signal=GPXTI1
PC10.GPIO_Label=BTN_DSP_TOGGLE
PC10.Signal=GPXTI10
PC11.GPIO_Label=BTN_VVAR_TOGGLE
PC11.Signal=GPXTI11
PC12.GPIO_Label=BTN_5VB_TOGGLE
PC12.Signal=GPXTI12
PC13.GPIO_Label=NC
PC13.Signal=GPIO_Input
PC14-OSC32_IN.GPIO_Label=RCC_OSC32_IN
PC14-OSC32_IN.Signal=RCC_OSC32_IN
PC15-OSC32_OUT.GPIO_Label=RCC_OSC32_OUT
PC15-OSC32_OUT.Signal=RCC_OSC32_OUT
PC3.GPIO_Label=RTRY_CLK
PC3.Signal=GPIO_Input
PC4.GPIO_Label=NC
PC4.Signal=GPIO_Input
PC5.GPIO_Label=LED_DATA
PC5.Signal=GPIO_Output
PC6.GPIO_Label=NC
PC6.Signal=GPIO_Input
PC7.GPIO_Label=NC
PC7.Signal=GPIO_Input
PC8.Signal=I2C3_SCL
PC9.Signal=I2C3_SDA
PD2.GPIO_Label=BTN_3V3B_TOGGLE
PD2.Signal=GPXTI2
PF0-OSC_IN.GPIO_Label=RCC_OSC_IN
PF0-OSC_IN.Signal=RCC_OSC_IN
PF1-OSC_OUT.GPIO_Label=RCC_OSC_OUT
PF1-OSC_OUT.Signal=RCC_OSC_OUT
PG10-NRST.GPIO_Label=NC
PG10-NRST.Signal=GPIO_Input

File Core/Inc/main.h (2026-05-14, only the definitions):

#define NC_Pin GPIO_PIN_13
#define NC_GPIO_Port GPIOC
#define RCC_OSC32_IN_Pin GPIO_PIN_14
#define RCC_OSC32_IN_GPIO_Port GPIOC
#define RCC_OSC32_OUT_Pin GPIO_PIN_15
#define RCC_OSC32_OUT_GPIO_Port GPIOC
#define RCC_OSC_IN_Pin GPIO_PIN_0
#define RCC_OSC_IN_GPIO_Port GPIOF
#define RCC_OSC_OUT_Pin GPIO_PIN_1
#define RCC_OSC_OUT_GPIO_Port GPIOF
#define NCG10_Pin GPIO_PIN_10
#define NCG10_GPIO_Port GPIOG
#define NCC0_Pin GPIO_PIN_0
#define NCC0_GPIO_Port GPIOC
#define RTRY_SW_Pin GPIO_PIN_1
#define RTRY_SW_GPIO_Port GPIOC
#define RTRY_SW_EXTI_IRQn EXTI1_IRQn
#define RTRY_CLK_Pin GPIO_PIN_3
#define RTRY_CLK_GPIO_Port GPIOC
#define NCA0_Pin GPIO_PIN_0
#define NCA0_GPIO_Port GPIOA
#define NCA1_Pin GPIO_PIN_1
#define NCA1_GPIO_Port GPIOA
#define NCA2_Pin GPIO_PIN_2
#define NCA2_GPIO_Port GPIOA
#define NCA3_Pin GPIO_PIN_3
#define NCA3_GPIO_Port GPIOA
#define BUCK_VVAR_DAC_Pin GPIO_PIN_4
#define BUCK_VVAR_DAC_GPIO_Port GPIOA
#define BUCK_5V_DAC_Pin GPIO_PIN_5
#define BUCK_5V_DAC_GPIO_Port GPIOA
#define BUCK_3V3_DAC_Pin GPIO_PIN_6
#define BUCK_3V3_DAC_GPIO_Port GPIOA
#define NCA7_Pin GPIO_PIN_7
#define NCA7_GPIO_Port GPIOA
#define NCC4_Pin GPIO_PIN_4
#define NCC4_GPIO_Port GPIOC
#define LED_DATA_Pin GPIO_PIN_5
#define LED_DATA_GPIO_Port GPIOC
#define NCB0_Pin GPIO_PIN_0
#define NCB0_GPIO_Port GPIOB
#define NCB1_Pin GPIO_PIN_1
#define NCB1_GPIO_Port GPIOB
#define INA_5VB_ADC2_IN12_Pin GPIO_PIN_2
#define INA_5VB_ADC2_IN12_GPIO_Port GPIOB
#define FAN_TACH_TIM2CH3_Pin GPIO_PIN_10
#define FAN_TACH_TIM2CH3_GPIO_Port GPIOB
#define OPAMP_3V3B_ADC1_IN14_Pin GPIO_PIN_11
#define OPAMP_3V3B_ADC1_IN14_GPIO_Port GPIOB
#define OPAMP_3V3A_ADC1_IN11_Pin GPIO_PIN_12
#define OPAMP_3V3A_ADC1_IN11_GPIO_Port GPIOB
#define BUCK_5V_EN_Pin GPIO_PIN_13
#define BUCK_5V_EN_GPIO_Port GPIOB
#define BUCK_12V_EN_Pin GPIO_PIN_14
#define BUCK_12V_EN_GPIO_Port GPIOB
#define BUCK_VVAR_EN_Pin GPIO_PIN_15
#define BUCK_VVAR_EN_GPIO_Port GPIOB
#define NCC6_Pin GPIO_PIN_6
#define NCC6_GPIO_Port GPIOC
#define NCC7_Pin GPIO_PIN_7
#define NCC7_GPIO_Port GPIOC
#define INA_VVAR_ADC5_IN1_Pin GPIO_PIN_8
#define INA_VVAR_ADC5_IN1_GPIO_Port GPIOA
#define INA_20V_ADC5_IN2_Pin GPIO_PIN_9
#define INA_20V_ADC5_IN2_GPIO_Port GPIOA
#define NCA10_Pin GPIO_PIN_10
#define NCA10_GPIO_Port GPIOA
#define HSSW_5VB_Pin GPIO_PIN_11
#define HSSW_5VB_GPIO_Port GPIOA
#define HSSW_3V3B_Pin GPIO_PIN_12
#define HSSW_3V3B_GPIO_Port GPIOA
#define NCA15_Pin GPIO_PIN_15
#define NCA15_GPIO_Port GPIOA
#define BTN_DSP_TOGGLE_Pin GPIO_PIN_10
#define BTN_DSP_TOGGLE_GPIO_Port GPIOC
#define BTN_DSP_TOGGLE_EXTI_IRQn EXTI15_10_IRQn
#define BTN_VVAR_TOGGLE_Pin GPIO_PIN_11
#define BTN_VVAR_TOGGLE_GPIO_Port GPIOC
#define BTN_VVAR_TOGGLE_EXTI_IRQn EXTI15_10_IRQn
#define BTN_5VB_TOGGLE_Pin GPIO_PIN_12
#define BTN_5VB_TOGGLE_GPIO_Port GPIOC
#define BTN_5VB_TOGGLE_EXTI_IRQn EXTI15_10_IRQn
#define BTN_3V3B_TOGGLE_Pin GPIO_PIN_2
#define BTN_3V3B_TOGGLE_GPIO_Port GPIOD
#define BTN_3V3B_TOGGLE_EXTI_IRQn EXTI2_IRQn
#define T_SWO_Pin GPIO_PIN_3
#define T_SWO_GPIO_Port GPIOB
#define FAN_PWM_TIM3_CH1_Pin GPIO_PIN_4
#define FAN_PWM_TIM3_CH1_GPIO_Port GPIOB
#define NCB5_Pin GPIO_PIN_5
#define NCB5_GPIO_Port GPIOB
#define NCB6_Pin GPIO_PIN_6
#define NCB6_GPIO_Port GPIOB
#define NCB7_Pin GPIO_PIN_7
#define NCB7_GPIO_Port GPIOB
#define NCB8_Pin GPIO_PIN_8
#define NCB8_GPIO_Port GPIOB
#define NCB9_Pin GPIO_PIN_9
#define NCB9_GPIO_Port GPIOB

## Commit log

2026-04-29 update directory structure and add remaining datasheets (#2)
    * update directory structure and add remaining datasheets
    * starting pin assignments for drafting
    * continuing pin assignment drafting for schematic
    * all pins assigned for the completion of schematic
    * schematic first complete version pdf and imgs
    * commit first complete schematic version files
    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
    [buffer_fan_leds.kicad_sch, current_sensors.kicad_sch, microcontroller.kicad_sch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]
2026-05-01 updated schematic for LC filters and added voltage injection to other… (#4)
    * updated schematic for LC filters and added voltage injection to other bucks
    * rework buck resistor divider values + add fb injection to 3V3 and 5V rail bucks
    * remove redundant switches for variable rail
    * remove datasheets for components no longer used in rev A3
    ---------
    [buffer_fan_leds.kicad_sch, current_sensors.kicad_sch, microcontroller.kicad_sch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]
2026-05-08 Rev a4 (#8)
    * update schematic to fix power rail node and update resistors to reflect series to reach target dividers
    * rev 4A for schematic to reflect changes from assembling
    * update schematic and README
    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
    [buffer_fan_leds.kicad_sch, current_sensors.kicad_sch, microcontroller.kicad_sch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]
2026-05-09 C malecki #9 (#10)
    * move pins around for better proximity to connection in layout
    * initial pinout based on board layout
    * copy over some code from v1
    * move opamp pins
    [power_supply_v2.kicad_sch]
2026-05-09 fix unsaved local file
    [power_supply_v2.ioc]
2026-05-09 add mising bypass caps to INAs in schematic
    [power_supply_v2.kicad_sch]
2026-05-09 remove extra assigned ina pin and rename user labels
2026-05-09 add RC filter to INA outs and fix divider equation resistor variables
    [power_supply_v2.kicad_sch]
2026-05-09 add power test code
    [power_supply_v2.kicad_sch]
2026-05-09 configuring adcs for interrupts and dma
2026-05-13 fix missing pin assignment
    [power_supply_v2.kicad_sch]
2026-05-14 starting power control testing

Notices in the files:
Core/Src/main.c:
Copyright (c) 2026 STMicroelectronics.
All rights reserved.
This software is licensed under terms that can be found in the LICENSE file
